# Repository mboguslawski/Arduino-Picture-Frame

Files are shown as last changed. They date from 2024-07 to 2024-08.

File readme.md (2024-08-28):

# Arduino Picture Frame

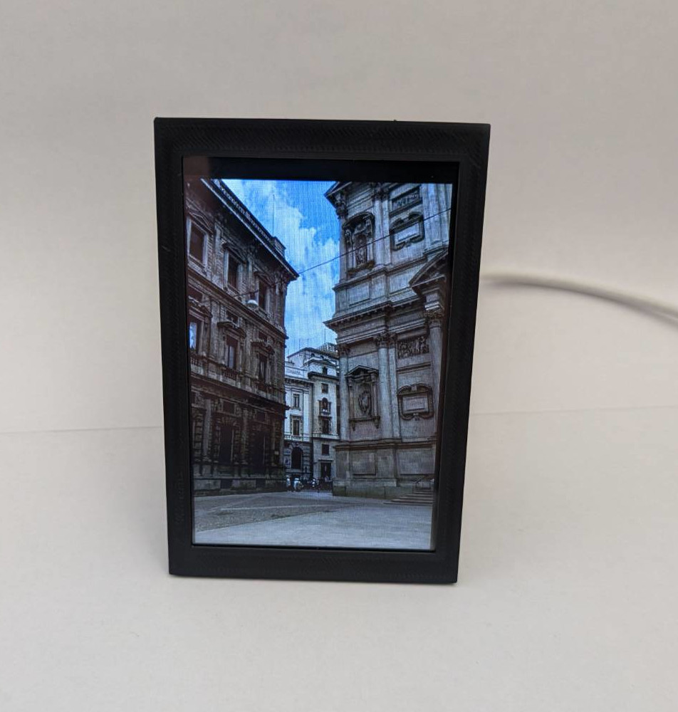
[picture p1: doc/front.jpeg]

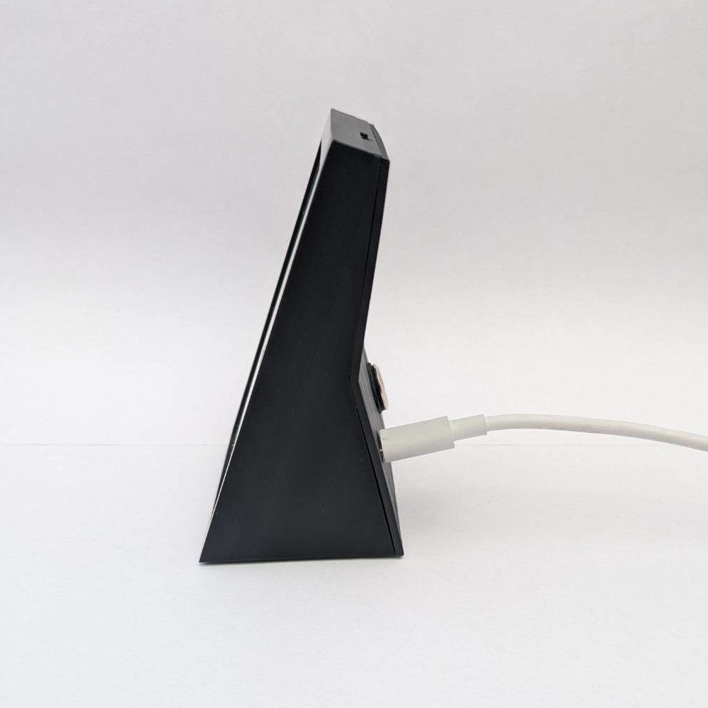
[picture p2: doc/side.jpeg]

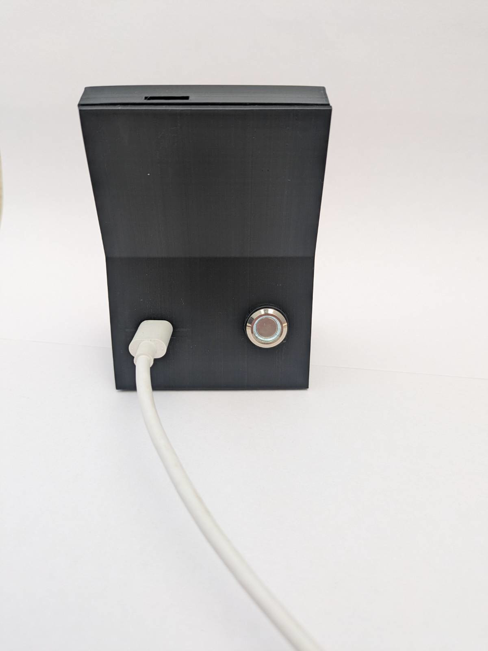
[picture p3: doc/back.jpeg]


## Features

Main feature is to display images loaded onto sd card.

Device is equipped with touch screen which is used to change settings.

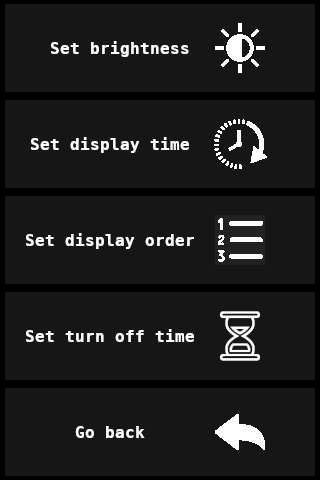
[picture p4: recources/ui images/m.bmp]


### 1. Changing brightness

Brightness can be changed with four levels, chosen brightness is saved to file with settings, so it will be applied automatically after startup.

### 2. Display time

Chose for how long single image is displayed, it is saved, so it will be applied automatically after startup.

### 3. Display order

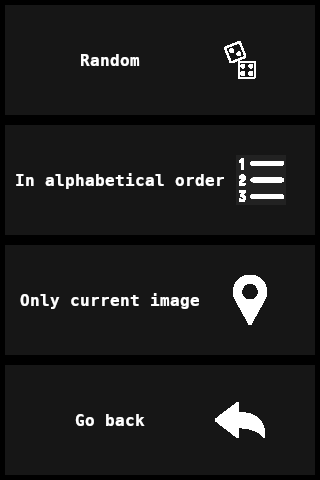
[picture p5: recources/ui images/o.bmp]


3 available display orders:
- **Random** \
Images are displayed in random order, special algorithm is used to ensure that different images will appear.

- **In alphabetical order** \
Images are displayed in order they are visible in folder on sd card.

- **Only current** \
After choosing this option only currently displayed image wil be shown (even after turning off and then turning device on again).

- **Set turn off time** \
Set time after which device will be in sleep mode (screen will be turned off). Touch the screen to awake device.

## Used hardware

**LCD screen** https://www.waveshare.com/4inch-tft-touch-shield.html \
**Arduino Pro Mini 5V** \
**USB C connector** https://botland.store/protoboard-connector-board-accessories/12658-usb-20-typ-c-connector-for-breadboard-pololu-2585-5904422319823.html \
**Power button** https://botland.store/switches-with-button/10799-on-off-bistable-switch-pbw-12a-2a-250v--5904422316648.html  
**Micro sd card** https://sandisk-store.pl/pl/p/SANDISK-ULTRA-ANDROID-microSDHC-32-GB-100MBs-Class-10-UHS-I/23078721

## Make one yourself

Case for device can be 3d printed using project available [here](./recources/case%203D%20print%20files/). Filament used can be bought [here](https://print-me.pl/sklep/produkty/hobby-design/pla/advanced-matt-pla/advanced-matt-pla-black-200g/).  
Printing setting:  
Nozzle temperature: 195 C  
Bed temperature: 60 C  
Layer height: 0.1 mm

**Connection for project**:

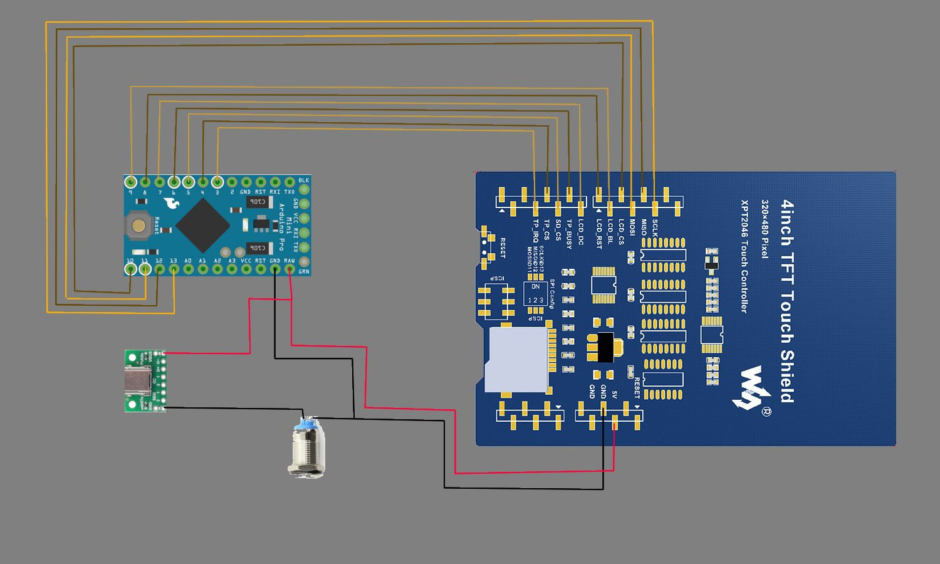
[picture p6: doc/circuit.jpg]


Additional led can be put into button and connected to arduino GND and VCC (via resistor).

Code can be uploaded to Arduino with PlatformIO extension for VSCodium or Arduino IDE.

#### SD card preparation

1. Upload **.bmp** images from [recourses](./recources/ui%20images/) to sd card
2. Put your images into **/images** folder on sd card

### Image format

Images must be in **24 bit** bmp format (**320px width**, **480px height**) \
In **/images** folder image name must be a number. \
For example 5 images must be named as following: \
0.bmp \
1.bmp \
2.bmp \
3.bmp \
4.bmp

## Author
#### Mateusz Bogusławski (E: mateusz.boguslawski@ibnet.pl)
##### (Case project) Artur Bogusławski (E: artur.boguslawski@ibnet.pl)

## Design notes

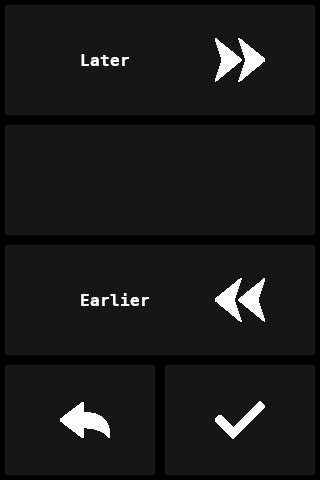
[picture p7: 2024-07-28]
recources/ui images/f.bmp

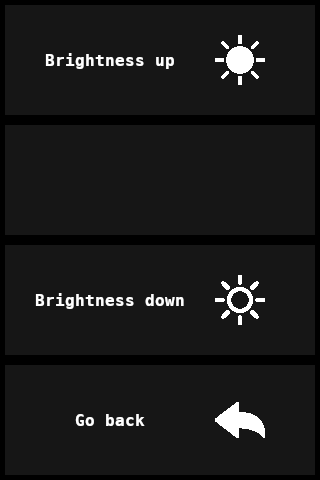
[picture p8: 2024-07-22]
recources/ui images/b.bmp

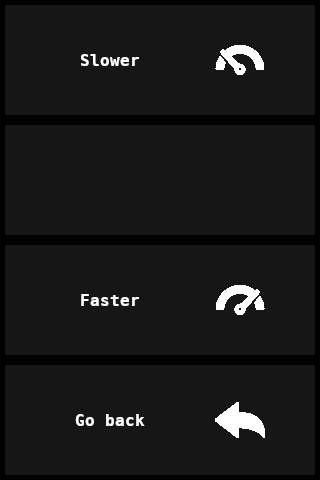
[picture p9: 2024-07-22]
recources/ui images/t.bmp

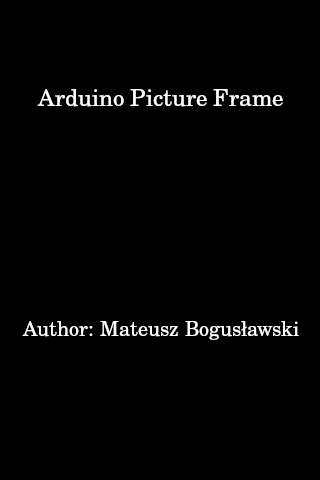
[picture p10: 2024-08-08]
recources/ui images/intro.bmp

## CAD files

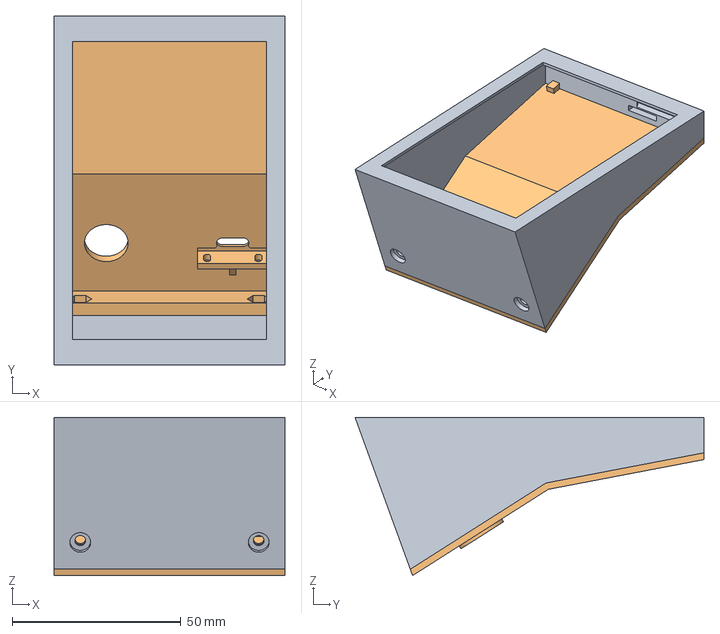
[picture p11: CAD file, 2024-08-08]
recources/case 3D print files/case&lid.step
68.5 x 103.5 x 46.9 mm

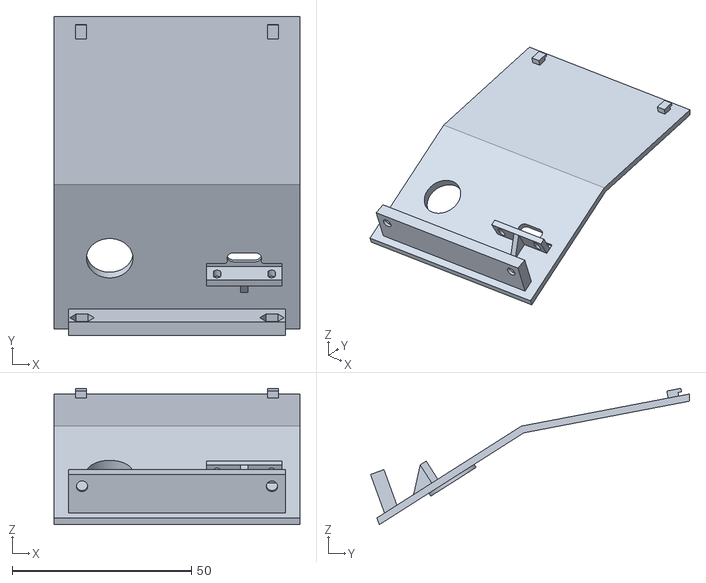
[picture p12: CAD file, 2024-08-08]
recources/case 3D print files/lid.stl
68.5 x 88.9 x 38.0

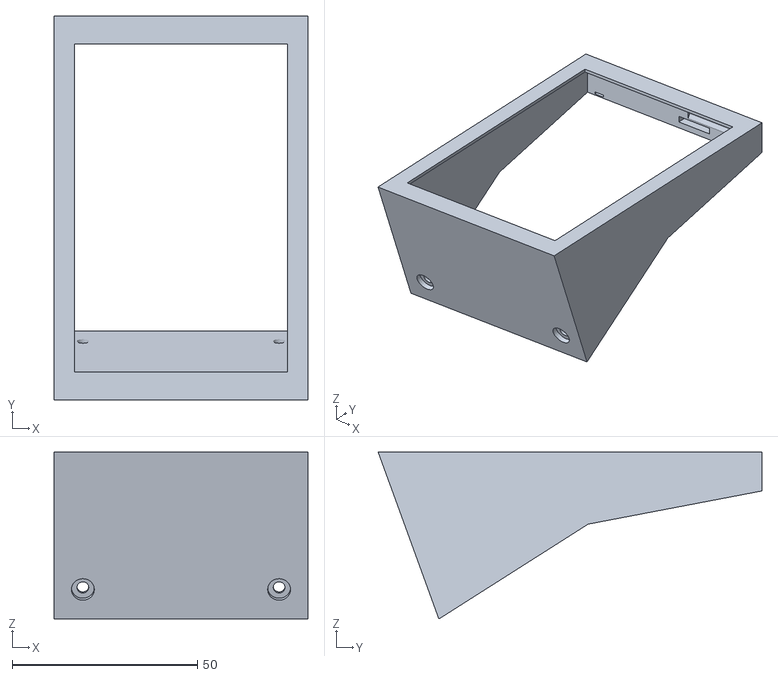
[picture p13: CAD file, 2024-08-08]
recources/case 3D print files/case.stl
68.5 x 103.5 x 45.0

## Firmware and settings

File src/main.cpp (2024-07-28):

/*
Copyright (C) 2024 Mateusz Bogusławski, E: mateusz.boguslawski@ibnet.pl

This program is free software: you can redistribute it and/or modify
it under the terms of the GNU General Public License as published by
the Free Software Foundation, either version 3 of the License, or
(at your option) any later version.
This program is distributed in the hope that it will be useful,
but WITHOUT ANY WARRANTY; without even the implied warranty of
MERCHANTABILITY or FITNESS FOR A PARTICULAR PURPOSE.  See the
GNU General Public License for more details.
You should have received a copy of the GNU General Public License
along with this program.  If not, see https://www.gnu.org/licenses/.
*/

#include <Arduino.h>
#include <ILI9486.h>
#include <XPT2046_Touchscreen.h>

#include "SDStorage/SDStorage.h"
#include "Calibration/Calibration.h"
#include "DigitalFrame/DigitalFrame.h"

#define IMAGE_DIR "/images"

// Pin configuration
#define ILI9486_CS 10
#define ILI9486_BL 9
#define ILI9486_RST 8
#define ILI9486_DC 7
#define XPT2046_CS 4
#define XPT2046_IRQ 3

// XPT2046 touch coordinates calibration 
#define X_BEGIN 555
#define X_END 3551
#define Y_BEGIN 3783
#define Y_END 392

ILI9486 *display;
XPT2046_Touchscreen *touch;
Calibration *calibration;
SDStorage *storage;
DigitalFrame *frame;

void setup() {
	display = new ILI9486(ILI9486_CS, ILI9486_BL, ILI9486_RST, ILI9486_DC, ILI9486::R2L_U2D, 0, ILI9486_BLACK);

	digitalWrite(ILI9486_CS, 1);
	digitalWrite(4, 1);
	storage = new SDStorage(5, display->getWidth(), display->getHeight(), IMAGE_DIR);
	
	touch = new XPT2046_Touchscreen(XPT2046_CS, XPT2046_IRQ);
	touch->begin();

	calibration = new Calibration(true, display, touch);
	calibration->calibrate(X_BEGIN, X_END, Y_BEGIN, Y_END);

	frame = new DigitalFrame(display, touch, calibration, storage);
}

void loop() {
	frame->loop();
}

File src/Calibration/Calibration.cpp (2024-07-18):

/*
Calibration.cpp
Calibration class implementation.

Copyright (C) 2024 Mateusz Bogusławski, E: mateusz.boguslawski@ibnet.pl

This program is free software: you can redistribute it and/or modify
it under the terms of the GNU General Public License as published by
the Free Software Foundation, either version 3 of the License, or
(at your option) any later version.
This program is distributed in the hope that it will be useful,
but WITHOUT ANY WARRANTY; without even the implied warranty of
MERCHANTABILITY or FITNESS FOR A PARTICULAR PURPOSE.  See the
GNU General Public License for more details.
You should have received a copy of the GNU General Public License
along with this program.  If not, see https://www.gnu.org/licenses/.
*/

#include "Calibration.h"

Calibration::Calibration(bool swapxy, ILI9486 *display, XPT2046_Touchscreen *touch):
    swapxy(swapxy),
    display(display),
    touch(touch),
    xBegin(0),
    xEnd(0),
    yBegin(0),
    yEnd(0)
{}

void Calibration::calibrate() {
    // Coordinates of points to display
    const uint16_t left = 40;
    const uint16_t right = this->display->getWidth() - 40;
    const uint16_t bottom = 40;
    const uint16_t up = this->display->getHeight() - 40;
    const uint16_t size = 20;
    
    constexpr uint16_t touchDelay = 200;
    constexpr uint16_t repeat = 10;

    // 0-left bottom, 1-right bottom, 2-left up, 3-left up
    uint16_t positions[4][2] = {{left, bottom}, {right, bottom}, {left, up}, {right, up}};
    TS_Point points[4];


    // Draw points one by one
    display->clear(ILI9486_BLACK);
    for (uint8_t i = 0; i < 4; i++) {

        display->drawCircle(positions[i][0], positions[i][1], size, ILI9486_WHITE, true);
        
        // Repeat measure
        uint16_t x = 0, y = 0;
        for (uint8_t j = 0; j < repeat; j++) {
            delay(touchDelay);
            while (!touch->tirqTouched() || !touch->touched()) {} // Wait for touch

            TS_Point p = touch->getPoint();
            x += p.x;
            y += p.y;
        }

        display->drawCircle(positions[i][0], positions[i][1], size, ILI9486_BLACK, true);

        // Set point coordinates as average
        points[i].x = x / repeat;
        points[i].y = y / repeat;

        if (swapxy) { swapXY(points[i]); }
    }

    uint16_t xb = (points[0].x + points[2].x) / 2;
    uint16_t xe = (points[1].x + points[3].x) / 2;
    uint16_t yb = (points[0].y + points[1].y) / 2;
    uint16_t ye = (points[2].y + points[3].y) / 2;


    this->xBegin = map(0, positions[0][0], positions[1][0], xb, xe);
    this->xEnd = map(this->display->getWidth() - 1, positions[0][0], positions[1][0], xb, xe);

    this->yBegin = map(0, positions[0][1], positions[2][1], yb, ye);
    this->yEnd = map(this->display->getHeight() - 1, positions[0][1], positions[2][1], yb, ye);


    // Print calibration values
    if (Serial) {
        Serial.print("xBegin = ");
        Serial.println(xBegin);
        Serial.print("xEnd = ");
        Serial.println(xEnd);
        Serial.print("yBegin = ");
        Serial.println(yBegin);
        Serial.print("yEnd = ");
        Serial.println(yEnd);
    }

    display->clear();
}

void Calibration::calibrate(uint16_t xBegin, uint16_t xEnd, uint16_t yBegin, uint16_t yEnd) {
    this->xBegin = xBegin;
    this->xEnd = xEnd;
    this->yBegin = yBegin;
    this->yEnd = yEnd;
}

void Calibration::translate(TS_Point &point) {
    if (this->swapxy) {
        swapXY(point);
    }

    point.x = map(point.x, xBegin, xEnd, 0, this->display->getWidth() - 1);
    point.y = map(point.y, yBegin, yEnd, 0, this->display->getHeight() - 1);
}

void Calibration::swapXY(TS_Point &point) {
    int16_t tmp = point.x;
    point.x = point.y;
    point.y = tmp;
}

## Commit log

2024-07-17 Add Calibration class Simple example with calibration touch panel and display touch points
2024-07-18 Change calibration method
2024-07-18 Modify example to use constant calibration values
2024-07-18 Add clear button to program (display touch points)
2024-07-20 Pass pin numbers via ILI9486 constructor
2024-07-28 Improve sd errors handling
    [main.cpp]
2024-08-08 Add .stl files (case and lid)
    [case.stl, lid.stl]
2024-08-08 Add .step file (case and lid)
    [case&lid.step]
